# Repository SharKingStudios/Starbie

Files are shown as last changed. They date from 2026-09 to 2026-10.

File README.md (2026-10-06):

# Starbie

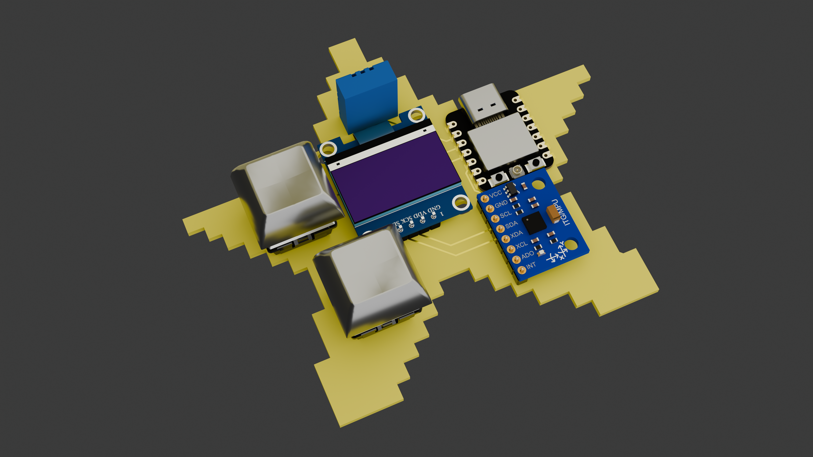
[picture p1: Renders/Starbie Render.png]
Starbie front render


Starbie is a tiny motion-controlled digital pet: basically a desktop Tamagotchi with minimal gameplay buttons. Instead of pressing controls, you interact with it by physically moving the board.

*Looking for the guide! You can find it [here](Week%201%20Guide.md)!*

## What it is

Starbie is designed to sit on your desk, show its personality on a small display, and react to how you handle it. Tilting, moving, and otherwise checking in on your pet are meant to be part of the experience.

The board includes a microcontroller, display, motion sensor, and environmental sensor in a compact PCB design. It is USB powered and built around beginner-friendly through-hole soldering for the add-on components.

## Why?

This project was created to be the week 1 beginner tutorial for [halflife](https://halflife.hackclub.com/)!

## Project status

The PCB design, renders, and an Arduino starter firmware are included here. The default program is a two-eye pet with a tilt-controlled radial menu, hidden stats, and a shake reaction.

## Software

[`Firmware/`](Firmware/) contains one self-contained Arduino IDE sketch for the XIAO ESP32-C3. Builders customize pins, menu actions, starting values, and motion settings together at the top of the sketch. The folder also includes a draggable [browser simulator](Firmware/simulator.html). See the [firmware README](Firmware/README.md) for setup notes.

## Repository contents

- `PCB/` - KiCad source files and fabrication exports
- `Renders/` - front and back PCB renders
- `Week 1 Guide.md` - project guide material
- `Firmware/` - Arduino IDE starter sketch

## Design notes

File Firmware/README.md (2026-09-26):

# Starbie firmware

Open [`Starbie/Starbie.ino`](Starbie/Starbie.ino) in Arduino IDE. It is the entire firmware in one beginner-editable file—there is no custom library or PlatformIO setup to manage.

The first part of the file is **BEGINNER SETTINGS**. It contains the pins, optional DHT11 switch, starting stats, radial-menu actions and reactions, motion settings, and the pet bitmap. The menu automatically treats the position where Button 1 opens it as centered; `SWAP_MPU_AXES`, `MENU_X_DIRECTION`, and `MENU_Y_DIRECTION` handle any physical MPU6050 orientation. Everything below that works automatically.

## Arduino IDE setup

1. In Arduino IDE, open **File → Preferences** and add this to **Additional Boards Manager URLs**:

   ```text
   https://espressif.github.io/arduino-esp32/package_esp32_index.json
   ```

2. Open **Tools → Board → Boards Manager**, search for `esp32`, and install **esp32 by Espressif Systems**.
3. Select **Tools → Board → esp32 → XIAO_ESP32C3** and select the board's port under **Tools → Port**.
4. Open **Sketch → Include Library → Manage Libraries** and install:

   - Adafruit GFX Library
   - Adafruit SSD1306
   - Adafruit MPU6050
   - DHT sensor library

   If Arduino asks to install dependencies, choose **Install All**.
5. Open `Starbie.ino`, press the arrow-shaped **Upload** button, and wait for the upload to finish.

Seeed's XIAO ESP32-C3 setup guide also confirms selecting `XIAO_ESP32C3` from the ESP32 Arduino board list. [Seeed Studio guide](https://wiki.seeedstudio.com/XIAO_ESP32C3_Getting_Started/)

## Controls

- **Button 1:** open the radial menu. Tilt in an action's general direction to select its full sector, then press Button 1 again to select it.
- **Button 2:** show or hide the stats screen. It never changes the pet.
- **Shake:** the only action that works naturally outside the menu.

The normal screen is a wandering 32 x 32, one-bit version of the supplied character. **NAP** freezes it in place with drifting `z`s, **PLAY** runs two fast left-to-right-to-left laps with hearts, **PET** sends hearts upward, and other actions do a tiny side-to-side shake followed by a jump. A shake wakes a sleeping pet early. Values only appear on the stats screen.

The final word in each menu line selects the visual reaction: `NAP_REACTION`, `JUMP_REACTION`, `HEART_REACTION`, or `RUN_REACTION`.

## Change the bitmap pet

The supplied art is a 32 x 32 black-and-white sprite named `PET_SPRITE` near the top of `Starbie.ino`.

To make your own, first create a high-contrast black-and-white image at the size you want. Keep its width divisible by 8; `32 x 32` is a friendly starting size. Then open [image2cpp](https://javl.github.io/image2cpp/), a browser tool that turns an image into an Arduino byte array. Use its **Horizontal 1 bit per pixel** output for an Adafruit GFX `drawBitmap` image. If the preview looks inverted, use image2cpp's invert option.

Replace an entire sprite definition, including its `{ ... }` byte list, and keep its name:

```cpp
const int PET_SPRITE_WIDTH = 32;
const int PET_SPRITE_HEIGHT = 32;

const uint8_t PROGMEM PET_SPRITE[] = {
  // Paste the bytes image2cpp gave you here.
};
```

Update `PET_SPRITE_WIDTH` and `PET_SPRITE_HEIGHT` whenever your image size changes. The browser simulator uses the matching starter sprite, so it is useful for seeing the reactions before uploading.

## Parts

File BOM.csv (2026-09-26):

Item | amount | cost (ea.) | Link
XIAO ESP32 C3 | 1 | 5.00 | https://www.seeedstudio.com/Seeed-XIAO-ESP32C3-p-5431.html
0.96 OLED | 1 | 2.50 | https://www.amazon.com/dp/B0GBVWBWCR
MPU6050 | 1 | 2.29 | https://www.amazon.com/dp/B0943SGP34
DHT11 | 1 | 3.33 | https://www.amazon.com/dp/B0BLG7R99R
MX Switches | 4 | 0.18 | https://www.amazon.com//dp/B0FQP8VYX4
Keycaps | 4 | 0.60 | https://www.amazon.com/dp/B0CQ2VLMVY
10k Resistor | 1 | 0.05 | https://www.amazon.com/dp/B0B4JFPHTW
PCB | 1 | 10.00 | https://www.jlcpcb.com/
Total (each kit) | 1 | 24.95

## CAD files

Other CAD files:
Renders/Starbie.blend

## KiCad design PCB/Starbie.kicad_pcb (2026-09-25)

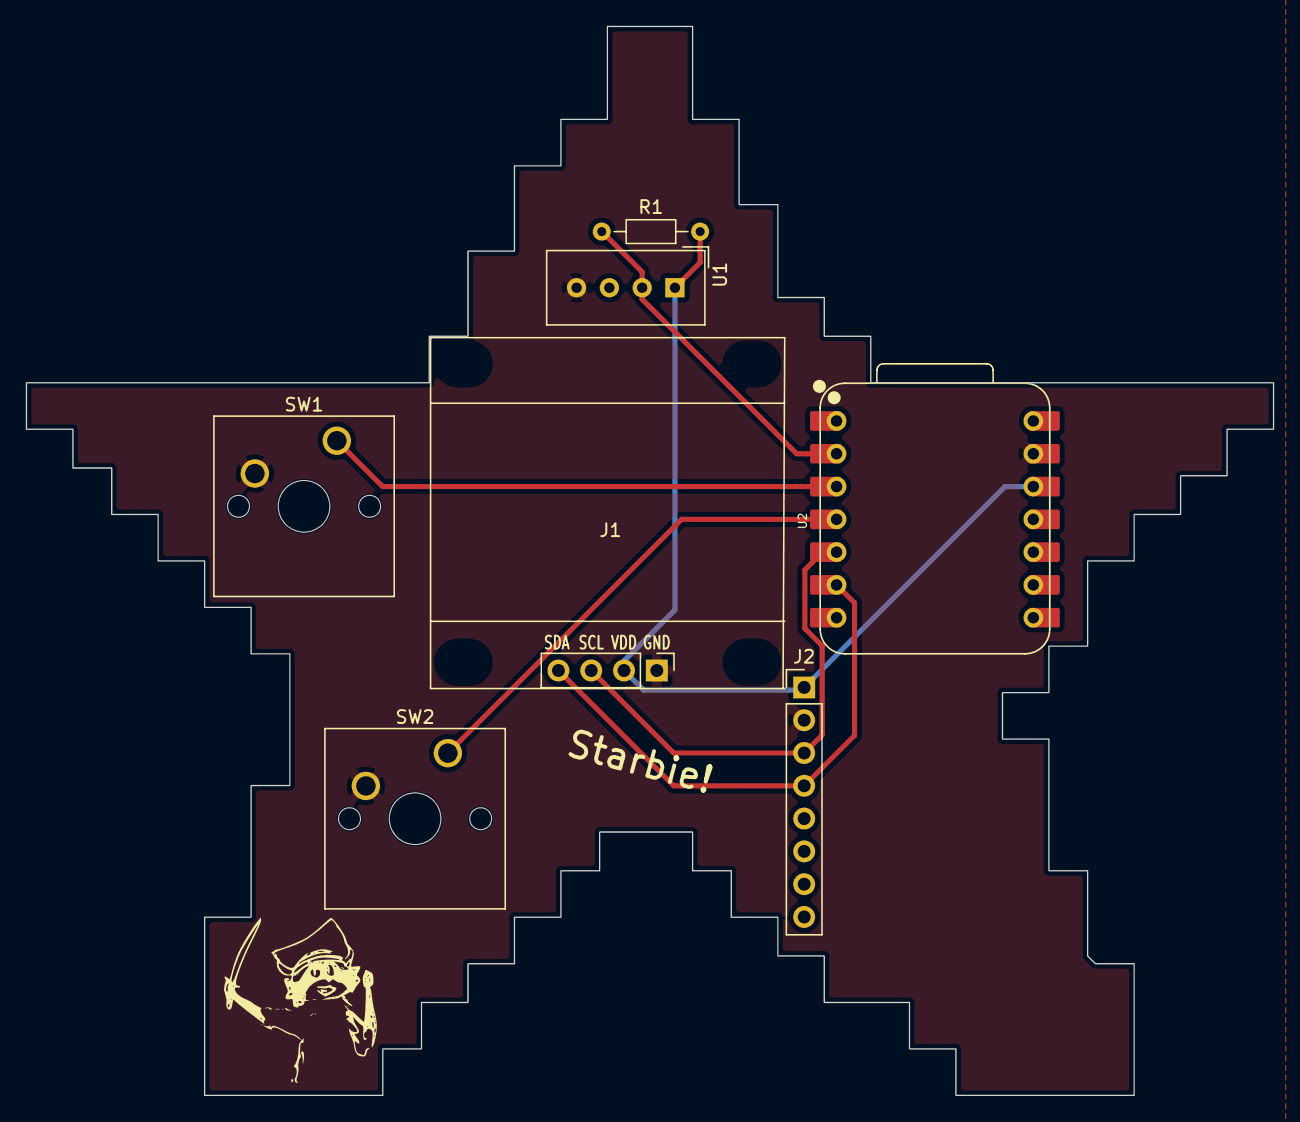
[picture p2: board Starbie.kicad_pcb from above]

Board: 2 copper layers, 96.6 x 82.8 mm, 7 parts (0 on the bottom side), 7 nets.

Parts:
J1: Conn_01x04_Pin; Display_128x64_096_I2C
J2: Conn_01x08_Pin; PinHeader_1x08_P2.54mm_Vertical
R1: 10k; R_Axial_DIN0204_L3.6mm_D1.6mm_P7.62mm_Horizontal
SW1, SW2: SW_Push; SW_Cherry_MX_1.00u_PCB
U1: DHT11; Aosong_DHT11_5.5x12.0_P2.54mm
U2: XIAO-ESP32-C3-SMD; XIAO-ESP32-C6-DIP

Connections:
+3.3V: J1.2, J2.1, R1.1, U1.1 (VDD), U2.12 (3V3_OUT)
/DHT11 DATA: R1.2, U1.2 (DATA), U2.2 (D1)
/GPIO2: SW1.1, U2.3 (D2)
/GPIO3: SW2.1, U2.4 (D3)
/SCL: J1.3, J2.3, U2.5 (D4)
/SDA: J1.4, J2.4, U2.6 (D5)
GND: J1.1, J2.2, SW1.2, SW2.2, U1.4 (GND), U2.13 (GND)

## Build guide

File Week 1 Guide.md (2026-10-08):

# How to make your own Starbie!

Hey there! Want to make your own Starbie but have no clue where to start? Right this way!

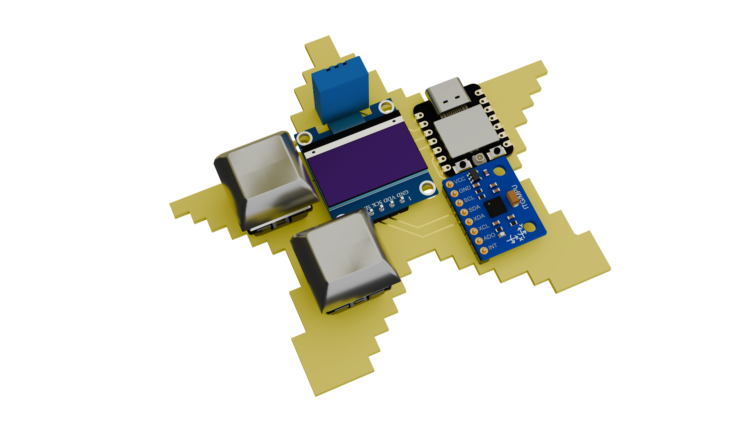
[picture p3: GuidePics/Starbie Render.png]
Starbie render


In this guide, we'll go over how to make a simple 2-key Starbie with an MPU6050 and DHT11 Environment Sensor, step by step.

This process will be in 2 main parts:

1. PCB Design
    1. Drawing the schematic
    2. PCB Layout
    3. Export
2. Firmware!

If anything is unclear, 9 times out of 10 you can usually google it; though PLEASE send what you're stuck on into #half-life!

First we will start with:

## Designing your PCB

For this guide we're going to be using [KiCad](https://www.kicad.org/), which is an open source PCB design tool.

To start, we're going to have to import the necessary footprints. For this guide, I've created a guide for you called [the care package](https://github.com/SharKingStudios/Starbie/blob/main/Week%201%20Care%20Package.zip)!

Once that's downloaded, you should end up with a file called "Week 1 Care Package.zip" - unzip that and you'll end up with a bunch of files like this:

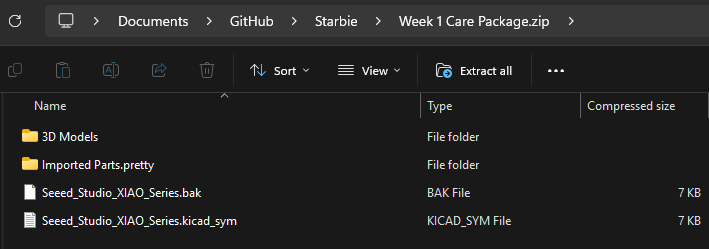
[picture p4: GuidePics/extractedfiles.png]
Extracted files


The .sym files are symbol libraries, while the .pretty folder contains the footprint libraries. **You'll have to search up how to install them - I find YouTube works best!**

## Schematic Editor

The schematic of a PCB is what defines all the different connections of your PCB, so we're going to start with it first!

First, open KiCad up KiCad and create a new project, then click on the "Schematic Editor" button:

Schematic editor

This should open up the schematic editor. Once you're in, press the A key on your keyboard. This should open up a menu where you can add add components.

Here we will be adding all the components we need. In the end you will end up with something like this:

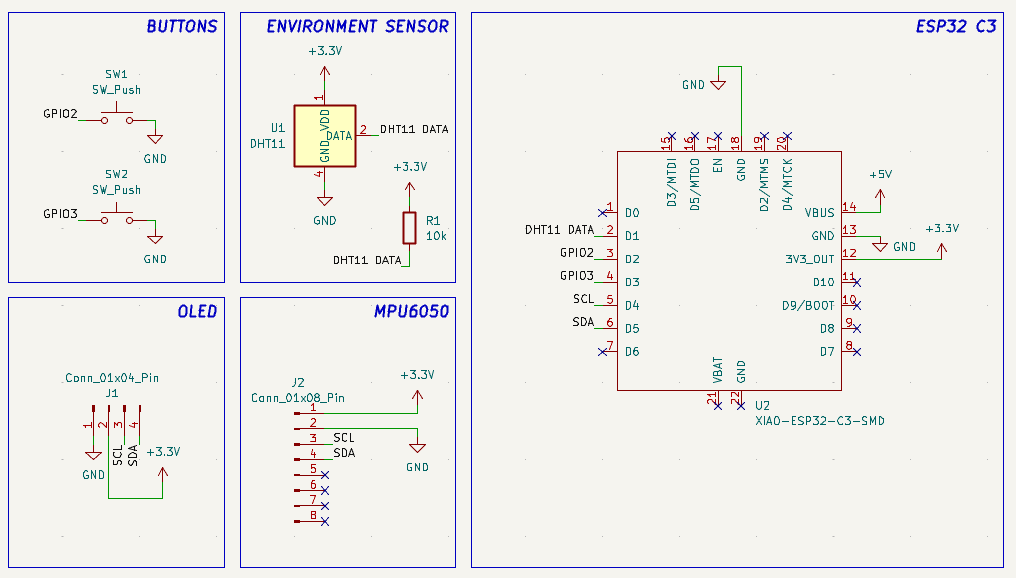
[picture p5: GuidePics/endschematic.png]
Final Schematic


Search for and add the XIAO-ESP32-C3 (This will be our microcontroller!)

Press P to add in the +5V, +3.3V and GND symbols.
Create a net label by pressing L on your keyboard and naming the net.

Finally wire all of those together like this:

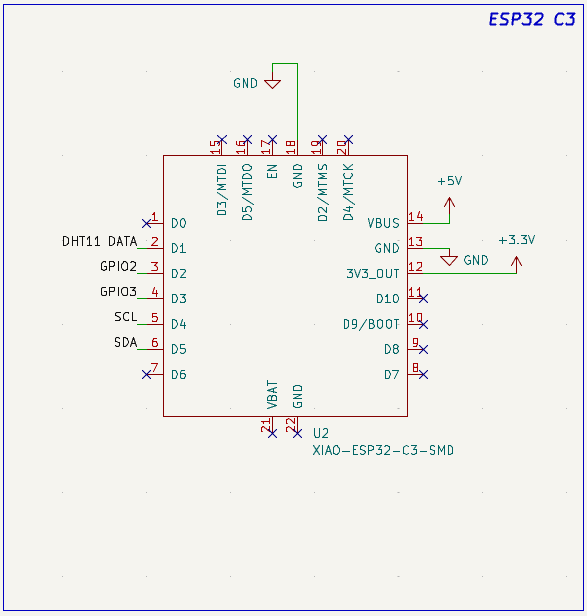
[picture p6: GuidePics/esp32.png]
ESP32


*(The net labels tell the schematic that those parts need to be connected without having to draw wires all over.)*

Next, we need to add in the buttons to allow for some interaction with our Starbie. (Add a SW_Push symbol.)

Connect one side of the button to a net and the other side to GND like this:

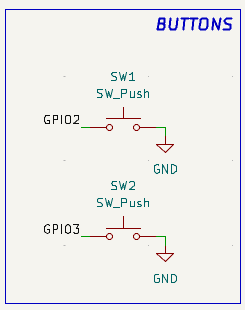
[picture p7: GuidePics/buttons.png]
Buttons


Next, we need to add the screen to display our character.

Search for a generic 01x04 pin and add that to your schematic, then wire it up like so:

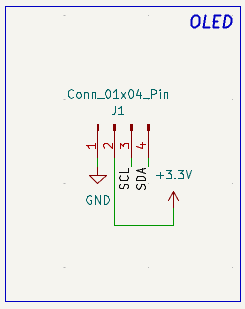
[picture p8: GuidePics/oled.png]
OLED


Next add in a generic 01x08 pin to represent the MPU6050 module. This will allow your Starbie to sense itself being moved around:

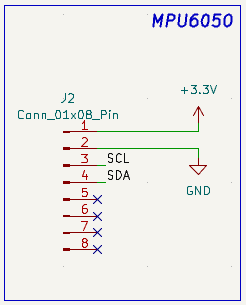
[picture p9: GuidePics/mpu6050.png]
MPU6050


Finally, add in the DHT11 sensor. This will allow your Starbie to sense the temperature and moisture of the environment. (Add a DHT11 symbol.)

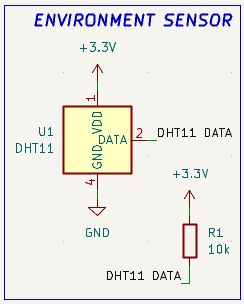
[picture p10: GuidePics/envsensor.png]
Environment sensor


Once all the components are connected, we can start assigning footprints to the symbols we have here. Footprints are what gets physically drawn on the PCB. To do this, click the "run footprint assignment tool" in the top right.

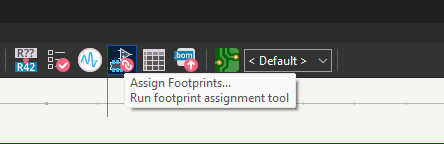
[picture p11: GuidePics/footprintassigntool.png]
Footprint Assign Tool


This should open up a window where you can assign different footprints to your components! Assign them based on the image below:

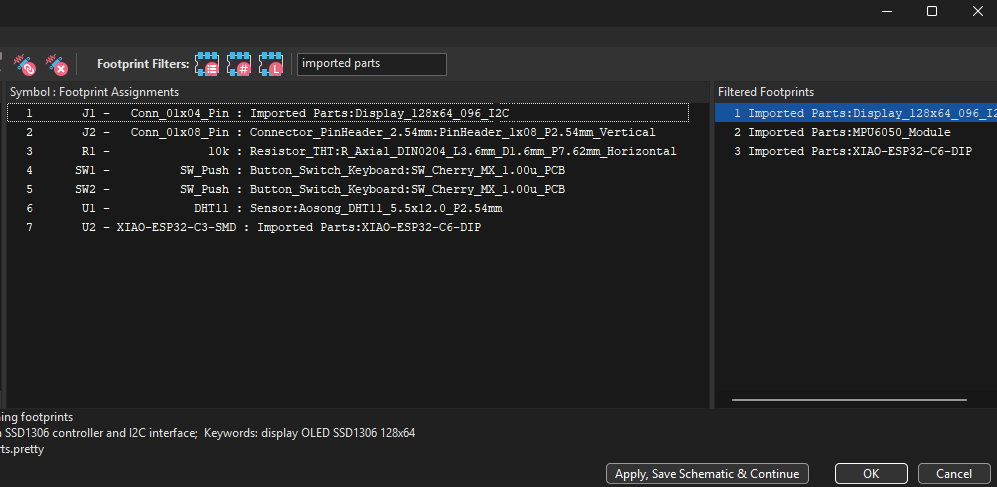
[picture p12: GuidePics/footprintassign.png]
Footprint Assign


(use the esp32c3 you imported from the Care Package!)

Once you're done, you can hit apply & save schematic. We're now officially done with the schematic! Onto making the physical PCB itself:

## Route the PCB

Go back to KiCad project page, and hit the "PCB editor" button. Once the PCB editor is open, hit the "Update PCB from schematic" button in the top right:

PCB editor

It should have dumped all the components on the page like this:

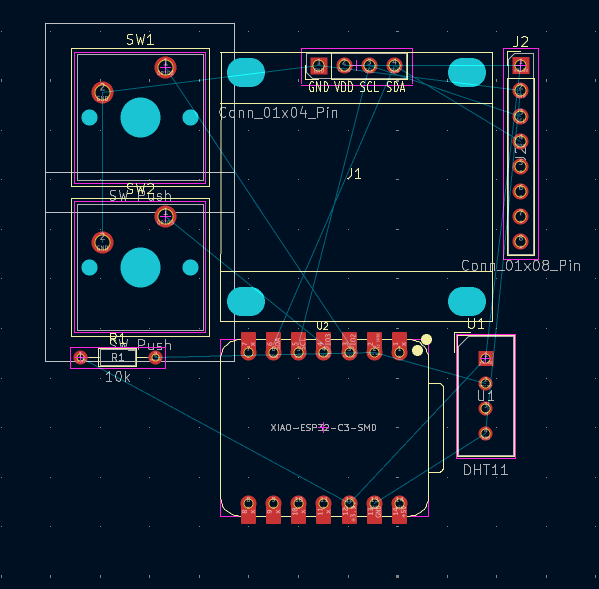
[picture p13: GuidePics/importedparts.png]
Imported parts


After that, create a custom boundry on the edge cuts layer (again Youtube is your friend here!) and arrange your components inside of it.

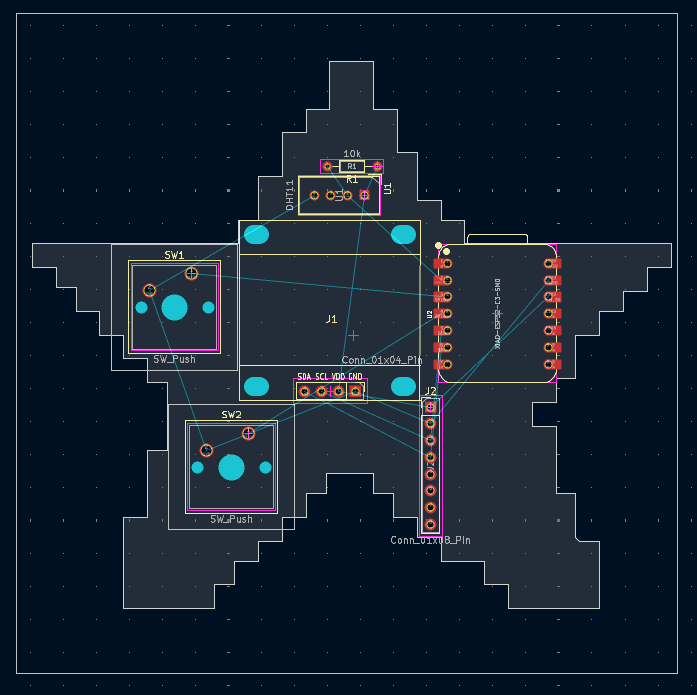
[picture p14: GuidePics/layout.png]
Layout


Now it's time to route the PCB! Hit X on your keyboard and hit any golden pad that still has a thin blue line. It should dim the entire screen and show you where to go. Route the PCB like so:

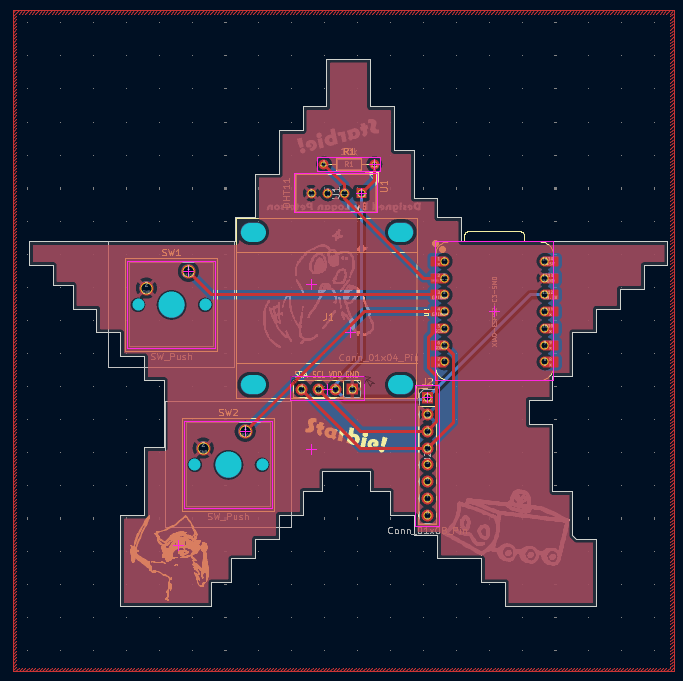
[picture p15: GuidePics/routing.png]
Routing


(to get the blue lines, change the layer on the right from F.cu to B.cu)

I've added a GND pour here, if you want more information about how you can use it you can check [this awesome tutorial](https://www.youtube.com/watch?v=DNTgrTukltw).

## Checking for errors:

DRC (or Design Rules Check) is a tool that automatically checks for PCB design mistakes, such as disconnected traces or other various errors.

You can access it via the button on the top right:

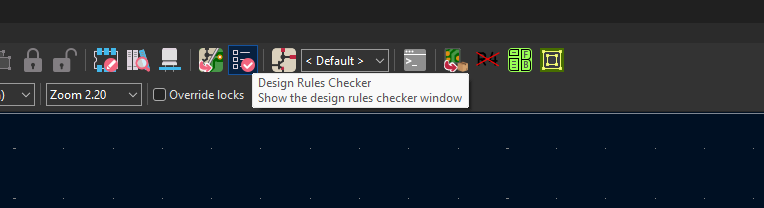
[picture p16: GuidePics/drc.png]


Try running it, you can ignore any warnings but you shouldnt have any errors except for these two:

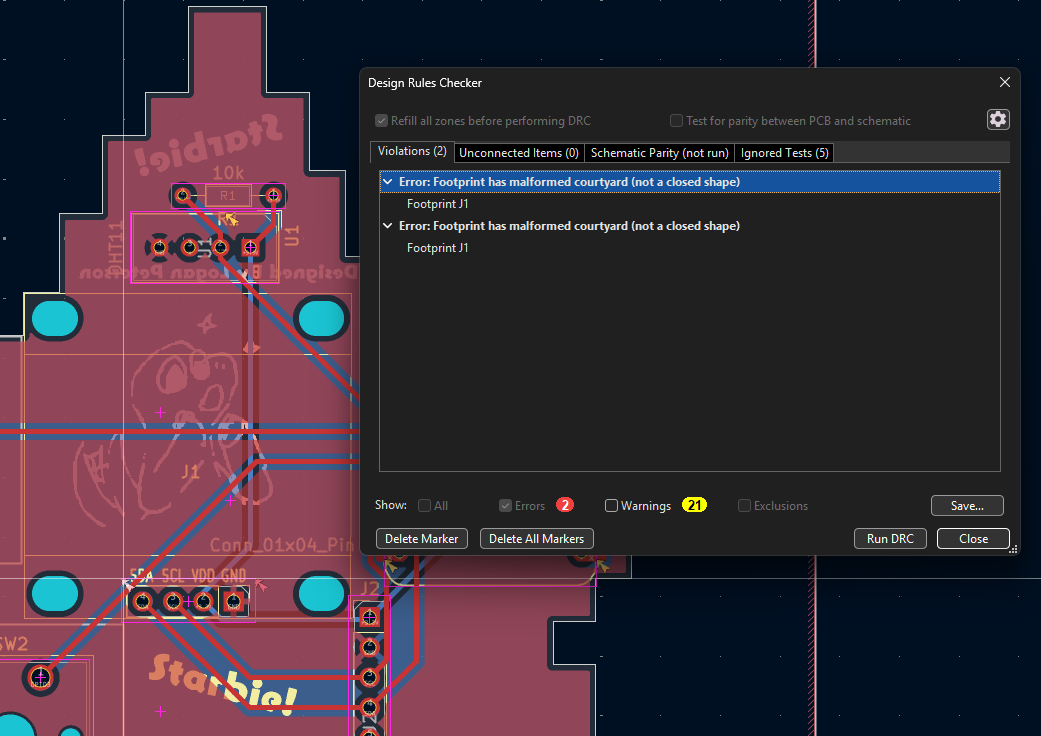
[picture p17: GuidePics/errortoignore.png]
Error to ignore


If the error is about a missing connection, go back and fix it!

Feel free to ask about any DRC errors you get in #half-life!

## Customization

Add some art or other cool things to your PCB by playing around with the Image Converter tool.

Google is your friend here, but you can probably figure it out by just messing around with it a bit!

Image converter

## Firmware

Now that you have a board designed, it needs a personality. Starbie's starter code is a single Arduino sketch: no VS Code extension, PlatformIO setup, or custom library required.

### Upload with Arduino IDE

The actual program is [Firmware/Starbie/Starbie.ino](Firmware/Starbie/Starbie.ino). Keep the Starbie folder and the Starbie.ino file together; Arduino IDE expects the sketch file to be inside a folder with the same name.

1. Install the current [Arduino IDE](https://www.arduino.cc/en/software).
2. Open **File → Preferences**. In **Additional Boards Manager URLs**, add:

   ~~~text
   https://espressif.github.io/arduino-esp32/package_esp32_index.json
   ~~~

3. Open **Tools → Board → Boards Manager**, search for esp32, and install **esp32 by Espressif Systems**.
4. Under **Tools → Board → esp32**, select **XIAO_ESP32C3**.
5. Open **Sketch → Include Library → Manage Libraries**. Install these libraries one at a time:

   - Adafruit GFX Library
   - Adafruit SSD1306
   - Adafruit MPU6050
   - DHT sensor library

   If Arduino asks to install dependencies, choose **Install All**.

6. Open Starbie.ino. (When you get your board, click Arduino's arrow-shaped **Upload** button.)

The ESP32 package URL, ESP32 Boards Manager install, and XIAO_ESP32C3 board selection are documented by [Espressif](https://docs.espressif.com/projects/arduino-esp32/en/latest/installing.html) and [Seeed Studio](https://wiki.seeedstudio.com/XIAO_ESP32C3_Getting_Started/).

### Controls

| Control | What it does |
| --- | --- |
| Button 1, first press | Opens the radial menu |
| Tilt while menu is open | Moves the selector ball; each general direction is one large sector |
| Button 1, second press | Chooses the highlighted action |
| Button 2 | Shows or hides the stats screen |
| Shake while seeing the pet | Gives Starbie its shake reaction |

The normal screen deliberately has no name or visible values—just the wandering pet. **NAP** stops it and emits drifting `z`s until it wakes after a short time or a shake. **PLAY** makes it sprint two quick left-to-right-to-left laps with hearts, while **PET** makes hearts float upward. Other actions do a short wiggle and jump.

### Make it yours

Nearly everything you need is together at the top of [Starbie.ino](Firmware/Starbie/Starbie.ino), inside the **BEGINNER SETTINGS** block. The one optional effect challenge below tells you exactly where to make its two edits.

#### 1. Match your own wiring

These are the pins for this guide's board:

| Part | XIAO label | ESP32-C3 GPIO |
| --- | --- | --- |
| OLED SDA and MPU6050 SDA | D4 | GPIO6 |
| OLED SCL and MPU6050 SCL | D5 | GPIO7 |
| DHT11 data | D1 | GPIO3 |
| Button 1 | D2 | GPIO4 |
| Button 2 | D3 | GPIO5 |

Change only the pin constants near the top if your submission uses a different layout:

~~~cpp
const int I2C_SDA_PIN = 6;
const int I2C_SCL_PIN = 7;
const int DHT_PIN = 3;
const int BUTTON_ONE_PIN = 4;
const int BUTTON_TWO_PIN = 5;
~~~

The OLED and MPU6050 share the same I2C SDA and SCL wires. If your version has no DHT11, use this setting instead of deleting code:

~~~cpp
const bool USE_DHT11 = false;
~~~

#### 2. Change the radial menu

The menu has four choices: top, right, bottom, and left. Each line has a label, changes to joy/energy/fullness, and one visual reaction:

~~~cpp
const MenuItem MENU_ITEMS[] = {
  {"NAP",   1,  18, -4, NAP_REACTION},   // top
  {"PLAY", 12, -9, -5, RUN_REACTION},    // right
  {"FEED",  3,  2, 18, JUMP_REACTION},   // bottom
  {"PET",   7,  0,  0, HEART_REACTION},  // left
};
~~~

`NAP_REACTION` makes the pet sleep, `HEART_REACTION` sends hearts up from it, `JUMP_REACTION` does the small wiggle and jump, and `RUN_REACTION` makes it run two fast laps with hearts. For example, you could turn the left choice into a dance move:

~~~cpp
{"DANCE", 15, -12, -3, JUMP_REACTION},  // left
~~~

Keep the menu at four items for now—the drawing code is set up for one item in each direction. Make the labels short so they fit in the OLED boxes.

#### 3. Add one special effect

Make your Starbie do one thing the starter code does not: give it a sparkle trail. This is only two small edits, and you can change the shape afterward to make it yours.

First, find `void drawHeart` lower in the file. Paste this **above** it:

~~~cpp
void drawSparkle(int x, int y) {
  display.drawPixel(x, y - 2, SSD1306_WHITE);
  display.drawPixel(x - 1, y - 1, SSD1306_WHITE);
  display.drawPixel(x + 1, y - 1, SSD1306_WHITE);
  display.drawPixel(x - 2, y, SSD1306_WHITE);
  display.drawPixel(x, y, SSD1306_WHITE);
  display.drawPixel(x + 2, y, SSD1306_WHITE);
  display.drawPixel(x - 1, y + 1, SSD1306_WHITE);
  display.drawPixel(x + 1, y + 1, SSD1306_WHITE);
  display.drawPixel(x, y + 2, SSD1306_WHITE);
}
~~~

Then find the `display.drawBitmap(...)` line inside `drawPet()`. Add this immediately below it:

~~~cpp
if (!isNapping() && (now / 250) % 2 == 0) {
  drawSparkle(petX - 4, petY + 18);
}
~~~

Upload after your board is built to see the little sparkle blink behind Starbie as it walks. Try changing the pixels in `drawSparkle` into a star, leaf, music note, or anything else that suits your pet.

#### 4. Draw your own bitmap pet

The starter pet is a 32 x 32 pixel, one-bit simplification of the supplied character. Its sprite is near the top of the sketch as `PET_SPRITE`. It wanders across the screen when no reaction is playing.

To use your own art, make a simple black-and-white image first. Keep the width divisible by 8; 32 x 32 is an easy first size. Upload it to [image2cpp](https://javl.github.io/image2cpp/), choose its **Horizontal 1 bit per pixel** output, and copy the Arduino byte array it creates. If your creature is the wrong color in the preview, use image2cpp's invert option.

Back in Starbie.ino, replace the full byte list inside one of the sprite definitions. Keep the name and update the size settings if your image is a different size:

~~~cpp
const int PET_SPRITE_WIDTH = 32;
const int PET_SPRITE_HEIGHT = 32;

const uint8_t PROGMEM PET_SPRITE[] = {
  // Paste image2cpp's bytes here.
};
~~~

## Next Steps

Now your done! Make sure all of your files are organized in your repository and that you have exported gerber files.
(Look up how to do this! Google is your friend)

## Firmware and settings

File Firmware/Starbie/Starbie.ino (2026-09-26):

/*
  Starbie: a tiny motion-controlled digital pet

  This is intentionally one file. Open this .ino file in Arduino IDE, edit
  the BEGINNER SETTINGS section, and upload it to a Seeed XIAO ESP32-C3.

  Install these libraries with Sketch > Include Library > Manage Libraries:
    - Adafruit GFX Library
    - Adafruit SSD1306
    - Adafruit MPU6050
    - DHT sensor library
  Arduino IDE will offer to install their dependencies too. Click Install All.
*/

#include <Wire.h>
#include <Adafruit_GFX.h>
#include <Adafruit_SSD1306.h>
#include <Adafruit_MPU6050.h>
#include <DHT.h>
#include <Preferences.h>
#include <math.h>

// =========================== BEGINNER SETTINGS ===========================
// Everything most builders will want to customize is in this one section.

// --- Your board's pins ----------------------------------------------------
// These are ESP32-C3 GPIO numbers, with the XIAO pin labels beside them.
const int I2C_SDA_PIN = 6;       // XIAO D4: OLED + MPU6050 SDA
const int I2C_SCL_PIN = 7;       // XIAO D5: OLED + MPU6050 SCL
const int DHT_PIN = 3;           // XIAO D1: DHT11 data
const int BUTTON_ONE_PIN = 4;    // XIAO D2: opens/confirms the radial menu
const int BUTTON_TWO_PIN = 5;    // XIAO D3: shows/hides stats

// Set this to false if your submission does not have a DHT11.
const bool USE_DHT11 = true;

// Most parts use these addresses. Only change them if an I2C scanner says
// your part is different (common OLED alternative: 0x3D).
const uint8_t OLED_ADDRESS = 0x3C;
const uint8_t MPU6050_ADDRESS = 0x68;

// --- Starting stats -------------------------------------------------------
// Stats are 0 to 100. They only change when you select an action or shake
// Starbie; nothing slowly drains while it sits on your desk.
const int STARTING_JOY = 70;
const int STARTING_ENERGY = 75;
const int STARTING_FULLNESS = 65;

// Set true, upload once, then set it back to false if you want a fresh pet.
const bool RESET_SAVED_PET_ON_BOOT = false;

// --- Radial menu ----------------------------------------------------------
// These four actions appear at TOP, RIGHT, BOTTOM, then LEFT in the menu.
// The last word controls the matching little visual reaction.
enum PetReaction {
  NAP_REACTION,
  JUMP_REACTION,
  HEART_REACTION,
  RUN_REACTION,
};

struct MenuItem {
  const char *label;
  int joyChange;
  int energyChange;
  int fullnessChange;
  PetReaction reaction;
};

const MenuItem MENU_ITEMS[] = {
  {"NAP",   1,  18, -4, NAP_REACTION},   // top: sleep and emit Zs
  {"PLAY", 12, -9, -5, RUN_REACTION},    // right: two fast laps + hearts
  {"FEED",  3,  2,  18, JUMP_REACTION},  // bottom: wiggle and jump
  {"PET",   7,  0,  0, HEART_REACTION},  // left: jump and emit hearts
};
const int MENU_ITEM_COUNT = sizeof(MENU_ITEMS) / sizeof(MENU_ITEMS[0]);

// --- Movement feel --------------------------------------------------------
// Bigger MENU_TILT_LIMIT makes the menu ball move less.
const float MENU_TILT_LIMIT = 6.0f;

// MPU6050 orientation: change these settings instead of rewiring your board.
// 1. If the sensor is turned 90 degrees, set SWAP_MPU_AXES to true.
// 2. If a direction feels backwards, change that direction from 1.0f to -1.0f.
const bool SWAP_MPU_AXES = false;
const float MENU_X_DIRECTION = 1.0f;
const float MENU_Y_DIRECTION = -1.0f;

// A small dead zone makes the ball rest in the center until the board is tilted.
const float MENU_CENTER_DEADZONE = 0.8f;
const float SHAKE_THRESHOLD = 7.0f;

// Shake is the only movement that has an effect outside the radial menu.
const int SHAKE_JOY_CHANGE = 5;
const int SHAKE_ENERGY_CHANGE = -2;
const int SHAKE_FULLNESS_CHANGE = -1;

// --- Your pet's bitmap and animation -------------------------------------
// This is a simplified 32 by 32, one-bit version of the supplied character.
// You can replace it with your own art later; keep these size values matched
// to the sprite array you paste in.
const int PET_SPRITE_WIDTH = 32;
const int PET_SPRITE_HEIGHT = 32;

// The pet wanders unless it is asleep. A non-nap action does a tiny shake,
// then a jump, except PLAY which runs two fast laps.
const uint16_t PET_WALK_PIXEL_MS = 70;
const uint16_t PET_PRE_JUMP_MS = 230;
const uint16_t PET_JUMP_MS = 430;
const int PET_JUMP_HEIGHT = 16;
const uint32_t NAP_DURATION_MS = 48000;  // 48 seconds: four times the old nap.
const uint16_t HEARTS_DURATION_MS = 1600;
const uint16_t PLAY_LAP_MS = 800;
const uint8_t PLAY_LAP_COUNT = 2;

// Each byte stores eight pixels, left to right. This sparse outline keeps the
// supplied creature readable on a tiny, one-bit OLED: head, eye, legs, tail,
// and a small flower-like ear accent all stay separate instead of becoming a blob.
const uint8_t PROGMEM PET_SPRITE[] = {
  0x00, 0x00, 0x00, 0x00,
  0x00, 0x00, 0x00, 0x00,
  0x00, 0x00, 0x00, 0x00,
  0x00, 0x00, 0x00, 0x00,
  0x00, 0x00, 0x00, 0x00,
  0x00, 0x00, 0x00, 0x00,
  0x00, 0x70, 0x0a, 0x00,
  0x00, 0xf8, 0x1f, 0x00,
  0x00, 0x8c, 0x3f, 0x80,
  0x00, 0x43, 0xff, 0x00,
  0x00, 0x43, 0xff, 0x00,
  0x00, 0x30, 0x7e, 0x00,
  0x00, 0x98, 0x01, 0x00,
  0x01, 0x98, 0x01, 0x80,
  0x03, 0x00, 0x10, 0xc0,
  0x03, 0x04, 0x00, 0xc0,
  0x01, 0x8b, 0x01, 0x80,
  0x01, 0xcb, 0x03, 0x80,
  0x03, 0xc0, 0x03, 0xc0,
  0x03, 0xc0, 0x03, 0xc0,
  0x01, 0xc0, 0x03, 0x80,
  0x01, 0x80, 0x01, 0x80,
  0x00, 0x60, 0x06, 0x00,
  0x00, 0x3f, 0xfc, 0x00,
  0x00, 0x7f, 0xfe, 0x00,
  0x00, 0x70, 0x0e, 0x00,
  0x00, 0x00, 0x00, 0x00,
  0x00, 0x00, 0x00, 0x00,
  0x00, 0x00, 0x00, 0x00,
  0x00, 0x00, 0x00, 0x00,
  0x00, 0x00, 0x00, 0x00,
  0x00, 0x00, 0x00, 0x00,
};
// ===========================================================================
// You can read below without needing to understand every line. The rest of
// the sketch handles buttons, sensors, drawing, and saving automatically.

const int SCREEN_WIDTH = 128;
const int SCREEN_HEIGHT = 64;
const int MENU_CENTER_X = 64;
const int MENU_CENTER_Y = 32;
const int MENU_ITEM_X[] = {64, 108, 64, 20};
const int MENU_ITEM_Y[] = {12, 32, 53, 32};
const int MENU_BALL_X_RANGE = 37;
const int MENU_BALL_Y_RANGE = 22;
const uint16_t BUTTON_DEBOUNCE_MS = 30;
const uint16_t MPU_READ_INTERVAL_MS = 30;
const uint16_t DHT_READ_INTERVAL_MS = 2200;
const uint16_t SHAKE_COOLDOWN_MS = 650;
const float STANDARD_GRAVITY = 9.80665f;

Adafruit_SSD1306 display(SCREEN_WIDTH, SCREEN_HEIGHT, &Wire, -1);
Adafruit_MPU6050 mpu;
DHT dht(DHT_PIN, DHT11);
Preferences preferences;

struct PetState {
  int joy;
  int energy;
  int fullness;
};

struct ButtonState {
  int pin;
  bool stableState;
  bool lastRawState;
  uint32_t lastChangedAt;
};

enum View {
  PET_VIEW,
  MENU_VIEW,
  STATS_VIEW,
};

PetState pet = {STARTING_JOY, STARTING_ENERGY, STARTING_FULLNESS};
ButtonState buttonOne = {BUTTON_ONE_PIN, HIGH, HIGH, 0};
ButtonState buttonTwo = {BUTTON_TWO_PIN, HIGH, HIGH, 0};
View currentView = PET_VIEW;

bool mpuFound = false;
bool dhtFound = false;
float accelerationX = 0.0f;
float accelerationY = 0.0f;
float accelerationZ = STANDARD_GRAVITY;
float temperatureC = NAN;
float humidity = NAN;
float menuBallX = MENU_CENTER_X;
float menuBallY = MENU_CENTER_Y;
float menuCenterAccelerationX = 0.0f;
float menuCenterAccelerationY = 0.0f;
int selectedMenuItem = -1;
uint32_t lastMpuReadAt = 0;
uint32_t lastDhtReadAt = 0;
uint32_t lastShakeAt = 0;
uint32_t shakeAnimationEndsAt = 0;
uint32_t petJumpStartedAt = 0;
uint32_t nappingUntil = 0;
uint32_t heartAnimationEndsAt = 0;
uint32_t playRunStartedAt = 0;
int nappingPetX = 0;

int petWalkingX(uint32_t now);

int keepInRange(int value, int smallest, int largest) {
  return constrain(value, smallest, largest);
}

void changePet(int joyChange, int energyChange, int fullnessChange) {
  pet.joy = keepInRange(pet.joy + joyChange, 0, 100);
  pet.energy = keepInRange(pet.energy + energyChange, 0, 100);
  pet.fullness = keepInRange(pet.fullness + fullnessChange, 0, 100);
}

void loadPet() {
  preferences.begin("starbie", false);
  if (RESET_SAVED_PET_ON_BOOT) {
    preferences.clear();
  }
  pet.joy = preferences.getInt("joy", STARTING_JOY);
  pet.energy = preferences.getInt("energy", STARTING_ENERGY);
  pet.fullness = preferences.getInt("full", STARTING_FULLNESS);
}

void savePet() {
  preferences.putInt("joy", pet.joy);
  preferences.putInt("energy", pet.energy);
  preferences.putInt("full", pet.fullness);
}

void setUpButton(ButtonState &button) {
  pinMode(button.pin, INPUT_PULLUP);
  button.stableState = digitalRead(button.pin);
  button.lastRawState = button.stableState;
  button.lastChangedAt = millis();
}

// Returns true exactly once for each press, even if the switch bounces.
bool wasPressed(ButtonState &button) {
  const bool rawState = digitalRead(button.pin);
  const uint32_t now = millis();

  if (rawState != button.lastRawState) {
    button.lastRawState = rawState;
    button.lastChangedAt = now;
  }

  if (rawState != button.stableState &&
      now - button.lastChangedAt >= BUTTON_DEBOUNCE_MS) {
    button.stableState = rawState;
    return button.stableState == LOW;
  }

  return false;
}

void updateMpu() {
  if (!mpuFound || millis() - lastMpuReadAt < MPU_READ_INTERVAL_MS) {
    return;
  }
  lastMpuReadAt = millis();

  sensors_event_t acceleration;
  sensors_event_t gyro;
  sensors_event_t sensorTemperature;
  mpu.getEvent(&acceleration, &gyro, &sensorTemperature);
  accelerationX = acceleration.acceleration.x;
  accelerationY = acceleration.acceleration.y;
  accelerationZ = acceleration.acceleration.z;
}

void updateDht() {
  if (!dhtFound || millis() - lastDhtReadAt < DHT_READ_INTERVAL_MS) {
    return;
  }
  lastDhtReadAt = millis();

  const float newHumidity = dht.readHumidity();
  const float newTemperatureC = dht.readTemperature();
  if (!isnan(newHumidity)) {
    humidity = newHumidity;
  }
  if (!isnan(newTemperatureC)) {
    temperatureC = newTemperatureC;
  }
}

int petWalkingX(uint32_t now) {
  const int farthestX = SCREEN_WIDTH - PET_SPRITE_WIDTH;
  const uint32_t roundTrip = static_cast<uint32_t>(farthestX) * 2;
  const uint32_t step = (now / PET_WALK_PIXEL_MS) % roundTrip;
  return step <= farthestX ? step : roundTrip - step;
}

uint32_t playRunDuration() {
  return static_cast<uint32_t>(PLAY_LAP_MS) * PLAY_LAP_COUNT;
}

bool isNapping() {
  return nappingUntil != 0 && millis() < nappingUntil;
}

bool isPlaying() {
  return playRunStartedAt != 0 && millis() - playRunStartedAt < playRunDuration();
}

int playRunX(uint32_t now) {
  const int farthestX = SCREEN_WIDTH - PET_SPRITE_WIDTH;
  const uint32_t lapAge = (now - playRunStartedAt) % PLAY_LAP_MS;
  const float progress = static_cast<float>(lapAge) / PLAY_LAP_MS;
  return progress < 0.5f ? static_cast<int>(progress * 2.0f * farthestX)
                         : static_cast<int>((1.0f - progress) * 2.0f * farthestX);
}

void updatePetTimers() {
  if (nappingUntil != 0 && !isNapping()) {
    nappingUntil = 0;  // The pet wakes naturally when its nap time is over.
  }
  if (playRunStartedAt != 0 && !isPlaying()) {
    playRunStartedAt = 0;  // PLAY is exactly two left-to-right-to-left laps.
  }
}

// While the menu is open, the MPU6050 acts like a tiny air mouse. The position
// at the instant Button 1 opens the menu becomes the center for that menu use.
void updateMenuBall() {
  float xTilt = accelerationX - menuCenterAccelerationX;
  float yTilt = accelerationY - menuCenterAccelerationY;

  if (SWAP_MPU_AXES) {
    const float oldXTilt = xTilt;
    xTilt = yTilt;
    yTilt = oldXTilt;
  }
  xTilt = constrain(xTilt * MENU_X_DIRECTION, -MENU_TILT_LIMIT, MENU_TILT_LIMIT);
  yTilt = constrain(yTilt * MENU_Y_DIRECTION, -MENU_TILT_LIMIT, MENU_TILT_LIMIT);
  const float targetX = MENU_CENTER_X + (xTilt / MENU_TILT_LIMIT) * MENU_BALL_X_RANGE;
  const float targetY = MENU_CENTER_Y + (yTilt / MENU_TILT_LIMIT) * MENU_BALL_Y_RANGE;

  // This small amount of smoothing makes the ball feel less jittery.
  menuBallX += (targetX - menuBallX) * 0.20f;
  menuBallY += (targetY - menuBallY) * 0.20f;

  // The menu has four full sectors, not four tiny targets. Any tilt direction
  // past the center dead zone selects its matching top/right/bottom/left action.
  if (fabsf(xTilt) < MENU_CENTER_DEADZONE && fabsf(yTilt) < MENU_CENTER_DEADZONE) {
    selectedMenuItem = -1;
  } else if (fabsf(xTilt) > fabsf(yTilt)) {
    selectedMenuItem = xTilt > 0.0f ? 1 : 3;  // right or left
  } else {
    selectedMenuItem = yTilt > 0.0f ? 2 : 0;  // bottom or top
  }
}

void checkForShake() {
  if (!mpuFound || currentView != PET_VIEW) {
    return;
  }

  const float magnitude = sqrtf(accelerationX * accelerationX +
                                accelerationY * accelerationY +
                                accelerationZ * accelerationZ);
  const uint32_t now = millis();
  if (fabsf(magnitude - STANDARD_GRAVITY) >= SHAKE_THRESHOLD &&
      now - lastShakeAt >= SHAKE_COOLDOWN_MS) {
    lastShakeAt = now;
    nappingUntil = 0;  // A shake wakes a sleeping pet right away.
    shakeAnimationEndsAt = now + 350;
    changePet(SHAKE_JOY_CHANGE, SHAKE_ENERGY_CHANGE, SHAKE_FULLNESS_CHANGE);
    savePet();
  }
}

void openMenu() {
  currentView = MENU_VIEW;
  selectedMenuItem = -1;
  menuBallX = MENU_CENTER_X;
  menuBallY = MENU_CENTER_Y;
  // Calibrate here so every menu starts from however the builder is holding it.
  menuCenterAccelerationX = accelerationX;
  menuCenterAccelerationY = accelerationY;
}

void chooseMenuItem() {
  if (selectedMenuItem == -1) {
    return;  // Keep the menu open until the ball reaches a choice.
  }

  const MenuItem &item = MENU_ITEMS[selectedMenuItem];
  changePet(item.joyChange, item.energyChange, item.fullnessChange);
  savePet();
  const uint32_t now = millis();
  nappingUntil = 0;
  heartAnimationEndsAt = 0;
  playRunStartedAt = 0;

  if (item.reaction == NAP_REACTION) {
    petJumpStartedAt = 0;
    nappingPetX = petWalkingX(now);
    nappingUntil = now + NAP_DURATION_MS;
  } else if (item.reaction == RUN_REACTION) {
    petJumpStartedAt = 0;
    playRunStartedAt = now;
    heartAnimationEndsAt = now + playRunDuration();
  } else {
    // A confirmed action gets a little anticipation shake before the jump.
    petJumpStartedAt = now;
    if (item.reaction == HEART_REACTION) {
      heartAnimationEndsAt = now + HEARTS_DURATION_MS;
    }
  }
  currentView = PET_VIEW;
}

void handleButtons() {
  if (wasPressed(buttonOne)) {
    if (currentView == MENU_VIEW) {
      chooseMenuItem();
    } else {
      openMenu();
    }
  }

  if (wasPressed(buttonTwo)) {
    // Button 2 never changes the pet. It only lets you peek at the values.
    currentView = currentView == STATS_VIEW ? PET_VIEW : STATS_VIEW;
  }
}

void drawHeart(int x, int y) {
  // A tiny seven-pixel-wide heart that stays crisp on the OLED.
  display.fillRect(x - 2, y, 2, 2, SSD1306_WHITE);
  display.fillRect(x + 1, y, 2, 2, SSD1306_WHITE);
  display.fillRect(x - 3, y + 2, 7, 2, SSD1306_WHITE);
  display.fillRect(x - 2, y + 4, 5, 1, SSD1306_WHITE);
  display.fillRect(x - 1, y + 5, 3, 1, SSD1306_WHITE);
  display.drawPixel(x, y + 6, SSD1306_WHITE);
}

void drawHearts(uint32_t now, int petX, int petY) {
  if (now >= heartAnimationEndsAt) {
    return;
  }

  const float progress =
      1.0f - static_cast<float>(heartAnimationEndsAt - now) / HEARTS_DURATION_MS;
  const int rise = static_cast<int>(progress * 18.0f);
  drawHeart(petX + 10, petY - 3 - rise);
  drawHeart(petX + 22, petY - 9 - rise / 2);
}

void drawSleepZs(uint32_t now, int petX, int petY) {
  // The Zs float upward, then loop back down while the pet is napping.
  const int rise = static_cast<int>((now / 300UL) % 15UL);
  display.setTextSize(1);
  display.setTextColor(SSD1306_WHITE);
  display.setCursor(petX + 23, petY - 2 - rise);
  display.print("z");
  display.setCursor(petX + 28, petY - 8 - rise / 2);
  display.print("z");
}

void drawPet() {
  display.clearDisplay();

  const uint32_t now = millis();
  int petX = isNapping() ? nappingPetX : petWalkingX(now);
  if (isPlaying()) {
    petX = playRunX(now);
  }
  int petY = SCREEN_HEIGHT - PET_SPRITE_HEIGHT;

  // The pet always wanders except during a nap; PLAY temporarily takes over.
  if (now < shakeAnimationEndsAt) {
    petX += static_cast<int>(sinf(now / 18.0f) * 3.0f);
  }

  if (!isNapping() && petJumpStartedAt != 0) {
    const uint32_t animationAge = now - petJumpStartedAt;

    if (animationAge < PET_PRE_JUMP_MS) {
      petX += static_cast<int>(sinf(now / 16.0f) * 3.0f);
    } else if (animationAge < PET_PRE_JUMP_MS + PET_JUMP_MS) {
      const float jumpProgress =
          static_cast<float>(animationAge - PET_PRE_JUMP_MS) / PET_JUMP_MS;
      petY -= static_cast<int>(sinf(jumpProgress * PI) * PET_JUMP_HEIGHT);
    } else {
      petJumpStartedAt = 0;
    }
  }

  petX = constrain(petX, 0, SCREEN_WIDTH - PET_SPRITE_WIDTH);
  display.drawBitmap(petX, petY, PET_SPRITE, PET_SPRITE_WIDTH, PET_SPRITE_HEIGHT,
                     SSD1306_WHITE);

  if (isNapping()) {
    drawSleepZs(now, petX, petY);
  }
  drawHearts(now, petX, petY);
}

void drawMenuItem(int item) {
  const int boxWidth = 33;
  const int boxHeight = 12;
  const int boxX = MENU_ITEM_X[item] - boxWidth / 2;
  const int boxY = MENU_ITEM_Y[item] - boxHeight / 2;
  const bool isSelected = item == selectedMenuItem;

  if (isSelected) {
    display.fillRoundRect(boxX, boxY, boxWidth, boxHeight, 3, SSD1306_WHITE);
    display.setTextColor(SSD1306_BLACK);
  } else {
    display.drawRoundRect(boxX, boxY, boxWidth, boxHeight, 3, SSD1306_WHITE);
    display.setTextColor(SSD1306_WHITE);
  }

  display.setTextSize(1);
  const int labelLength = strlen(MENU_ITEMS[item].label);
  display.setCursor(MENU_ITEM_X[item] - labelLength * 3, MENU_ITEM_Y[item] - 3);
  display.print(MENU_ITEMS[item].label);
  display.setTextColor(SSD1306_WHITE);
}

void drawMenu() {
  display.clearDisplay();
  // The two diagonal lines divide the screen into four big selection sectors.
  display.drawLine(0, 0, SCREEN_WIDTH - 1, SCREEN_HEIGHT - 1, SSD1306_WHITE);
  display.drawLine(0, SCREEN_HEIGHT - 1, SCREEN_WIDTH - 1, 0, SSD1306_WHITE);
  for (int item = 0; item < MENU_ITEM_COUNT; item++) {
    drawMenuItem(item);
  }

  display.drawCircle(MENU_CENTER_X, MENU_CENTER_Y, 11, SSD1306_WHITE);
  display.fillCircle(static_cast<int>(menuBallX), static_cast<int>(menuBallY), 4,
                     SSD1306_WHITE);
}

void drawStatBar(int y, const char *label, int value) {
  display.setTextSize(1);
  display.setTextColor(SSD1306_WHITE);
  display.setCursor(4, y);
  display.print(label);
  display.drawRect(48, y, 57, 8, SSD1306_WHITE);
  display.fillRect(49, y + 1, map(value, 0, 100, 0, 55), 6, SSD1306_WHITE);
  display.setCursor(109, y);
  display.print(value);
}

void drawStats() {
  display.clearDisplay();
  drawStatBar(5, "JOY", pet.joy);
  drawStatBar(20, "ENERGY", pet.energy);
  drawStatBar(35, "FULL", pet.fullness);

  display.setCursor(4, 53);
  if (!isnan(temperatureC)) {
    display.print("TEMP ");
    display.print(static_cast<int>(temperatureC));
    display.print("C");
  } else {
    display.print("TEMP --");
  }

  display.setCursor(76, 53);
  if (!isnan(humidity)) {
    display.print("H ");
    display.print(static_cast<int>(humidity));
    display.print("%");
  } else {
    display.print("H --");
  }
}

void drawCurrentView() {
  if (currentView == MENU_VIEW) {
    drawMenu();
  } else if (currentView == STATS_VIEW) {
    drawStats();
  } else {
    drawPet();
  }
  display.display();
}

void setup() {
  Serial.begin(115200);
  Wire.begin(I2C_SDA_PIN, I2C_SCL_PIN);
  setUpButton(buttonOne);
  setUpButton(buttonTwo);
  loadPet();

  if (!display.begin(SSD1306_SWITCHCAPVCC, OLED_ADDRESS)) {
    Serial.println("OLED not found. Check power, GND, SDA, SCL, and address.");
    while (true) {
      delay(10);
    }
  }

  mpuFound = mpu.begin(MPU6050_ADDRESS, &Wire);
  if (mpuFound) {
    mpu.setAccelerometerRange(MPU6050_RANGE_8_G);
    mpu.setGyroRange(MPU6050_RANGE_500_DEG);
    mpu.setFilterBandwidth(MPU6050_BAND_21_HZ);
  } else {
    Serial.println("MPU6050 not found. The menu will not move until it is connected.");
  }

  if (USE_DHT11) {
    dht.begin();
    dhtFound = true;
  }

  drawCurrentView();
}

void loop() {
  updateMpu();
  updateDht();
  updatePetTimers();
  handleButtons();

  if (currentView == MENU_VIEW) {
    updateMenuBall();
  } else {
    checkForShake();
  }

  drawCurrentView();
  delay(16);  // Smooth display updates without making the code complicated.
}

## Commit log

2026-09-18 Designed Starbie PCB
    The whole thing.
    [Starbie.kicad_pcb, Starbie.kicad_sch]
2026-09-18 Add BOM
    [BOM.csv]
2026-09-25 Added Blender Renders
    [Starbie.blend, Starbie.kicad_pcb]
2026-09-26 Create Guide + New Renders
    [Starbie.blend]
2026-09-26 Updated BOM
    [BOM.csv]
2026-10-08 Update Guide
    Change the care package to include the xiao ESP32c3 instead of the ESP32c6. (While pin compatible, it was creating confusion)
2026-10-11 Swap I2C pins
